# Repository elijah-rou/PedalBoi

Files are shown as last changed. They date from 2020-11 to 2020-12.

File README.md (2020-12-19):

# PedalBoi
A guitar pedal powered by the [Electrosmith Daisy](https://www.electro-smith.com/daisy/daisy) microcontroller platform. The goal is to have a fully programmable pedal that can be customised with any effect via digital signal processing. The programmed effect is currently a distortion, hard clipping the input.

Why create something like this? Individual guitar pedals are quite expensive and the signal chain can get cumbersome/complex if you have many pedals. So being able to program any effect (or multiple), into a single pedal solves for both these things. Combined with on demand upload, this would be a great addition to a guitarist's arsenal!

## Functionality
### Core:
* ~~Circuit Design with Audio Buffers~~
* ~~Distortion Effect~~
*  ~~60Hz Noise removal~~
* ~~3PDT Switch Integration~~
*  ~~Initial prototype with premade enclosure~~
* Implement Potentiometer

### Future Work
* Create a PCB design with mountable female headers for the Daisy Seed and USB-C power delivery/USB passthrough
* Create a custom 3D (printable) enclusure
* Create mounting hardware for PCB and internal components for custom enclosure
* Implement bluetooth module for wireless effect uploading 
* Create web/app interface to facilitate wireless effect upload
* Live control of effect via an app

## Usage
Compile PedalBoi.
```makefile
make
```

Upload binary to Daisy.
```makefile
make program-dfu
```

## Bill of Materials and Schematic

### Documentation
For a detailed bill of core materials, consult this [document](bom.pdf).

Any enclosure may be used, such as the [aluminium console](https://www.digikey.com/en/products/detail/lmb-heeger-inc/MDC752-PLAIN/1738) which was chosen for the initial prototype.

### Current Circuit Schematic
The circuit consists of three major parts; the input buffer (left), the output buffer (right) and the Daisy seed microcontroller (middle). The schematic was created using [Fritzing](https://fritzing.org), check the program out! 
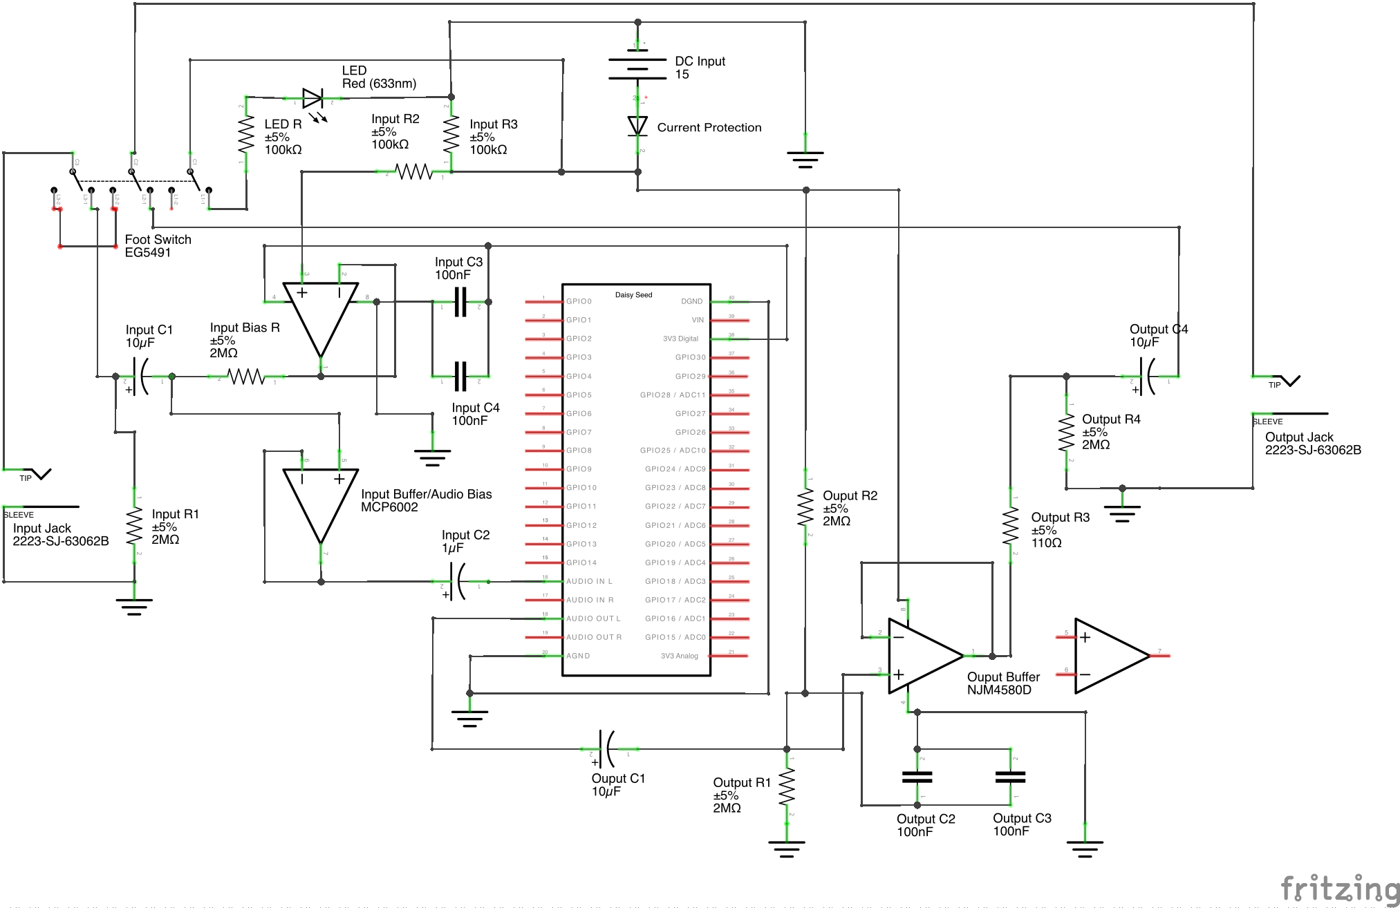
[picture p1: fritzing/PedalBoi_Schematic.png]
PedalBoi Circuit Schematic


### Material Motivation
The circuit was largely butchered from the [Daisy Petal schematic](https://github.com/electro-smith/Hardware/blob/master/reference/daisy_petal/ES_Daisy_Petal_Rev5.pdf) with most of the circuit design and components being the same, though it is heavily simplified and uses breadboard compatible components as opposed to TSSOP. This was mostly done as I had never designed an audio sensitive analog circuit like this before. With regards to casing and the footswitch, those were recommendations given by my Professor (thanks Wendy!)

The goal was to use as much established literature as I could in order to focus on actually building and refinining the pedal (as it turns out, analog electrical issues are hard and took up all my time).

## Major components

### Input Buffer
The first core component of the project is the input buffer circuit, which effectively allows us to take a high impedance signal and transform it into a low impedance signal. This is important as the pickups of any electric guitar are high impedance and do not allow much current to flow through them. Using the Op-Amps of the MCP6002 IC, we can both bias the input to a specific voltage and ensure that signal is unity gain. This results in a cleaner, undistorted signal.

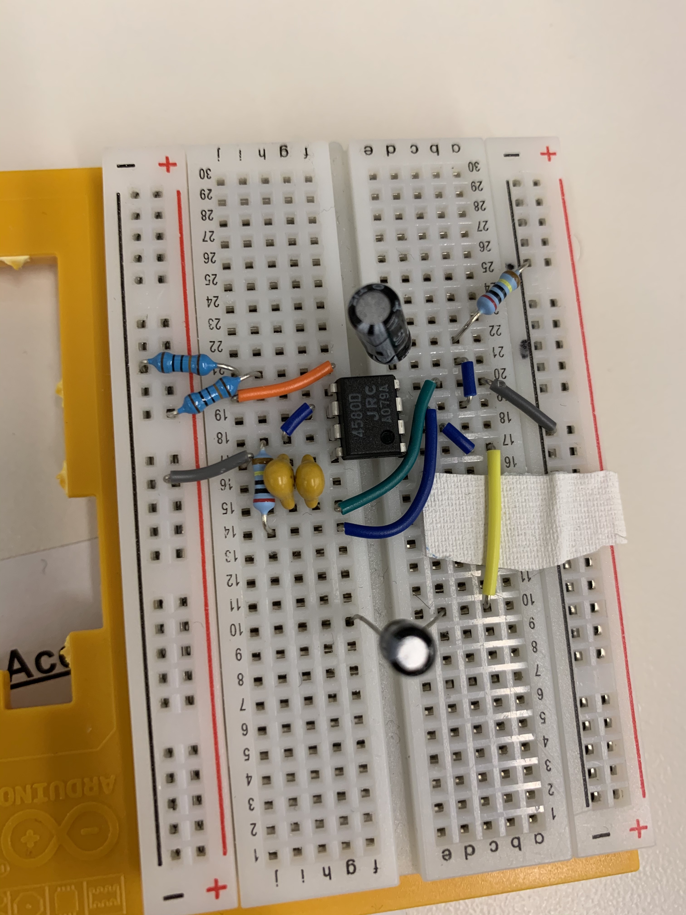
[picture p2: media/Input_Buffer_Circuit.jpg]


### Output Buffer
Similarly to the input buffer, the output buffer circuit ensures our signal remains at unity gain. In this case, we use an Op-Amp designed to handle higher voltage signals and spikes specifically for audio, allowing the circuit to handle effects like high-gain distortion.

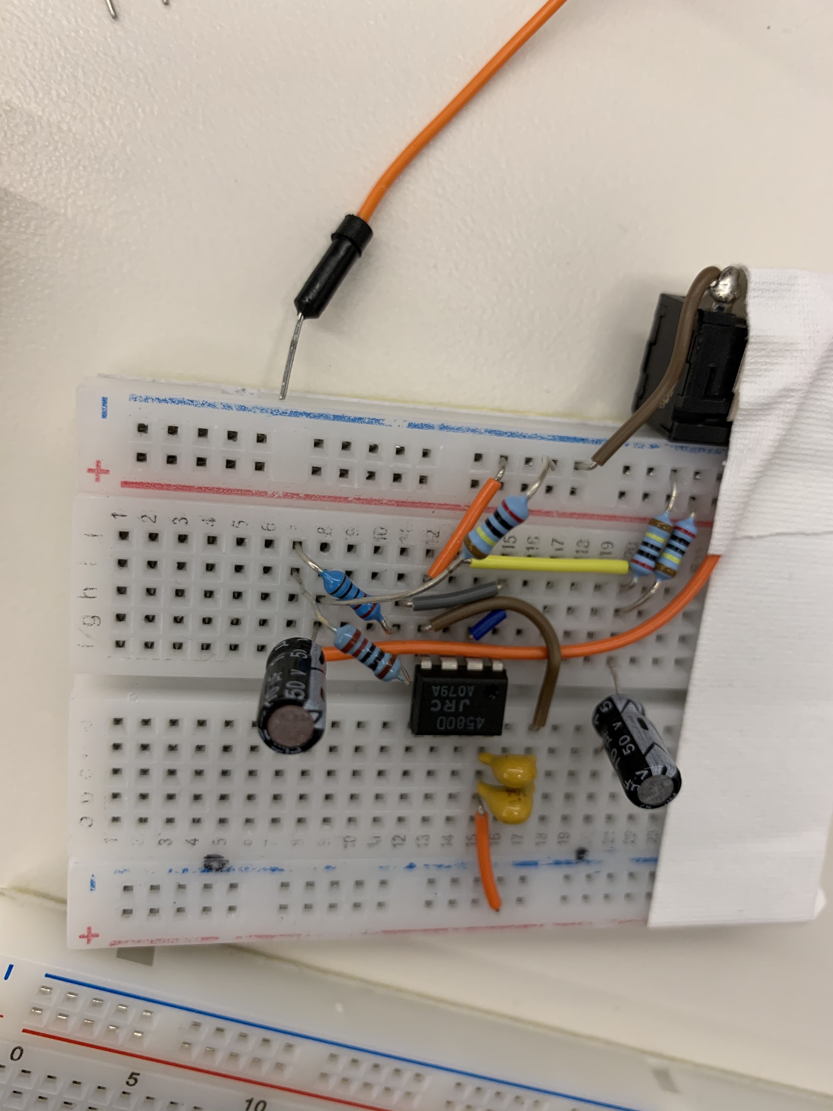
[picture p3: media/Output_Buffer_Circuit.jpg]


### 3PDT Switch
The 3PDT switch allows the input and output jacks to be directly wired to eachother when the switch is off, and connected to the processing circuit when the switch engaged. This is crucial in ensuring the least amount of noise possible when the pedal is off. A resource explaining how this is acheived can be found [here](https://www.coda-effects.com/2015/03/3pdt-and-true-bypass-wiring.html). 



### Enclosure
Points for mounting holes were determined via cross-section as shown in the photo below. For the V1 prototype, a drill with  tips matched to the component dimensions was used to create mounting holes on both the top half of the enclosure and the bottom half. Finally, the enclosure was brushed with sandpaper.

Top Half:
* 2 holes for the LED and potentiometer (to be implemented)
* One large hole for the footswitch

Bottom Half:
* 2 holes on either side for the input and output jacks.

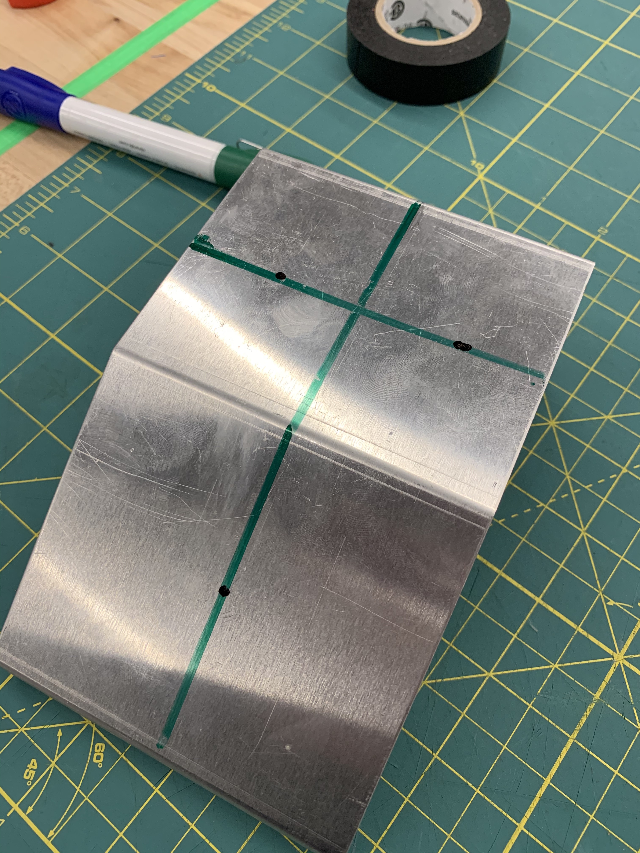
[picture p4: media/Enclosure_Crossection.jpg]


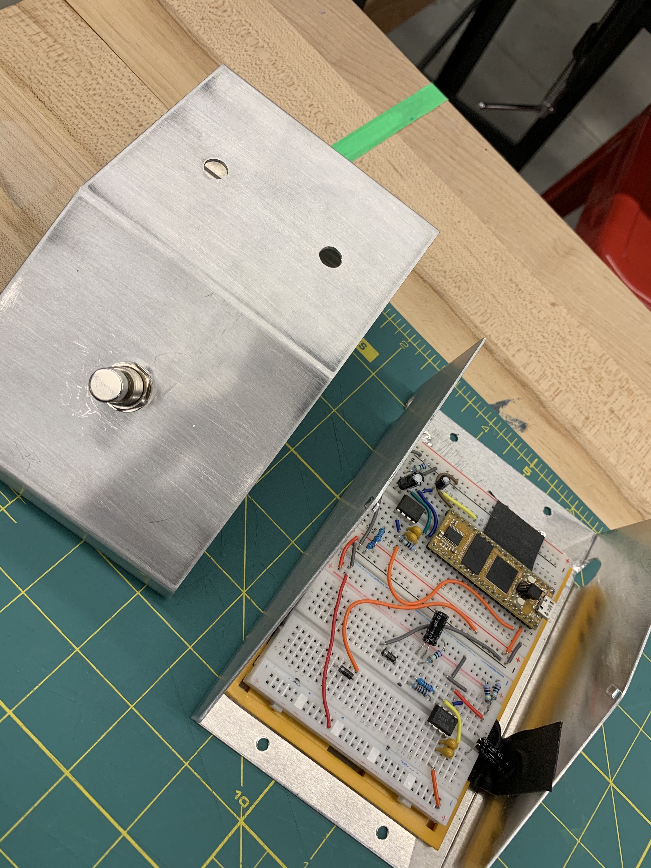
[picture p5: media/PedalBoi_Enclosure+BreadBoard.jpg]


### Daisy Seed
The Daisy Seed is a microcontroller specifically designed for audio processing and synthesis. It comes packaged with a variety of components needed for audio applications, including multiple Analog-Digital Converters, Digital-Analog Converters, (stereo) audio input/output and a fast M7 microprocessor with enourmous cache allowing for memory heavy effects such as complex *delay*. There are also an array of libraries included with the platform to both program the board and conduct DSP on analog input signals using C++. See [PedalBoi.cpp](PedalBoi.cpp) for distortion implementation details.

* Daisy Interface Library - [libdaisy](https://github.com/electro-smith/libDaisy)
* DSP Library - [DaisySP](https://github.com/electro-smith/DaisySP)



## Final Build
The final build comprised of the modified aluminium console containing the breadboard prototypes and 3PDT Switch, secured with 2 screws at the bottom of the console. Any 13-18V DC power source can be used to power the pedal via a positive and negative lead extending outside the case.


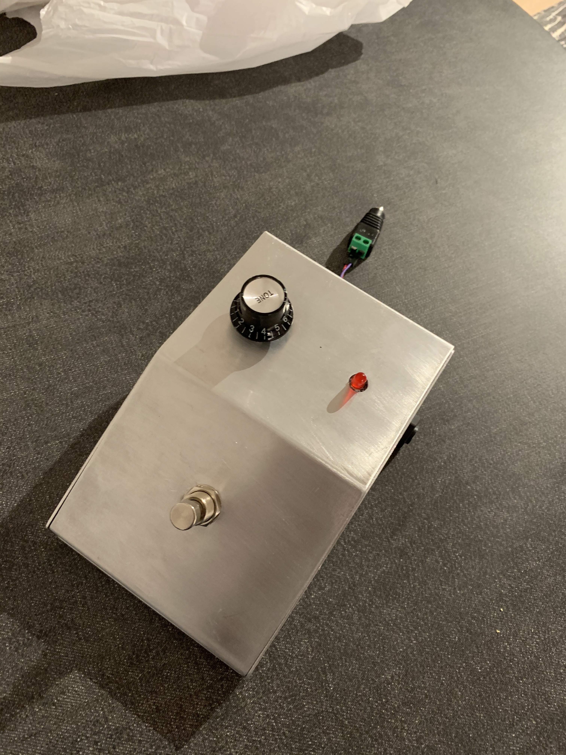
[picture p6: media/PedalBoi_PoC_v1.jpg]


## V1 Reflections
This was a great initial foray into processing real analog signals digitally and was lots of fun to build an initial proof of concept. However, there were a few significant issues throughout this V1 iteration:

### Ground loops
Ground loops caused by different AC power sources were a substantial source of noise in the initial design of the pedal. It was tough to analyse and debug where the noise was actually coming from. Eventually, the entire circuit had to be redesigned with the help of an Oscilloscope to weed out the hum.

### Incorrect Op-Amp functionality
The NJM4580D is a great Op-Amp for audio applications. However there is one substantial problem; it does not support rail-rail power. This proved to be an issue in the initial circuit design, which only supplied 5V via breadboard rails resulting in a power differential in the Op-Amp which caused it to malfunction. Luckily, the problem could be solved by applying more voltage over the NJM4580D Op-Amp, while simultaneously supplying the MCP6002 Op-Amps with the 3V3 supply directly from the Daisy Seed.

### Lack of space due to breadboards and prebuilt enclosure
As V1 used a prebuilt enclosure and a breadboard prototype, there was little space leftover for the audio jacks at the back of the case (resulting in the input audio jack being skew). This also made it impossible to mount the DC barrel plug inside the case, as the plug needed to be elevated. In the future, this can be solved with the combination of a custom PCB, custom enclosure and internal mounting brackets.

## Oscilloscope Breadboard Demo
Osc Demo (https://youtu.be/5Jb7ozU0aHI "Oscilloscope Demo")

## PedalBoi_v1 Demo:
v1 Demo (https://youtu.be/re2_l2MvA74 "PedalBoi_v1 Demo")

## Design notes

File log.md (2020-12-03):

## 13/11
Received initial components to prototype with.

This includes:
+ [Electrosmith Daisy Seed](https://www.electro-smith.com/daisy/daisy) 
+ Aluminium Console
+ [MCP6002-I/P-ND General Purpose OpAmp for input buffering](https://www.digikey.com/en/products/detail/microchip-technology/MCP6002-I-P/500875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)
+ [NJM4580D-ND Audio OpAmp for output buffering](https://www.digikey.com/en/products/detail/njr-corporation-njrc/NJM4580D/673772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)
+ [2 1/4" audio jacks (2223-SJ-63062B-ND)](https://www.digikey.com/en/products/detail/cui-devices/SJ-63062B/13155750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)

The initial plan is to build a simple circuit with OpAmps, the jacks and the 5V power supply I have, and have audio simply pass through the Daisy board. The next step will be to program an effect.

## 22/11
Designed initial simple prototype. Simply takes in an audio signal and outputs the same signal. See `prototype_1.asc` for sim.
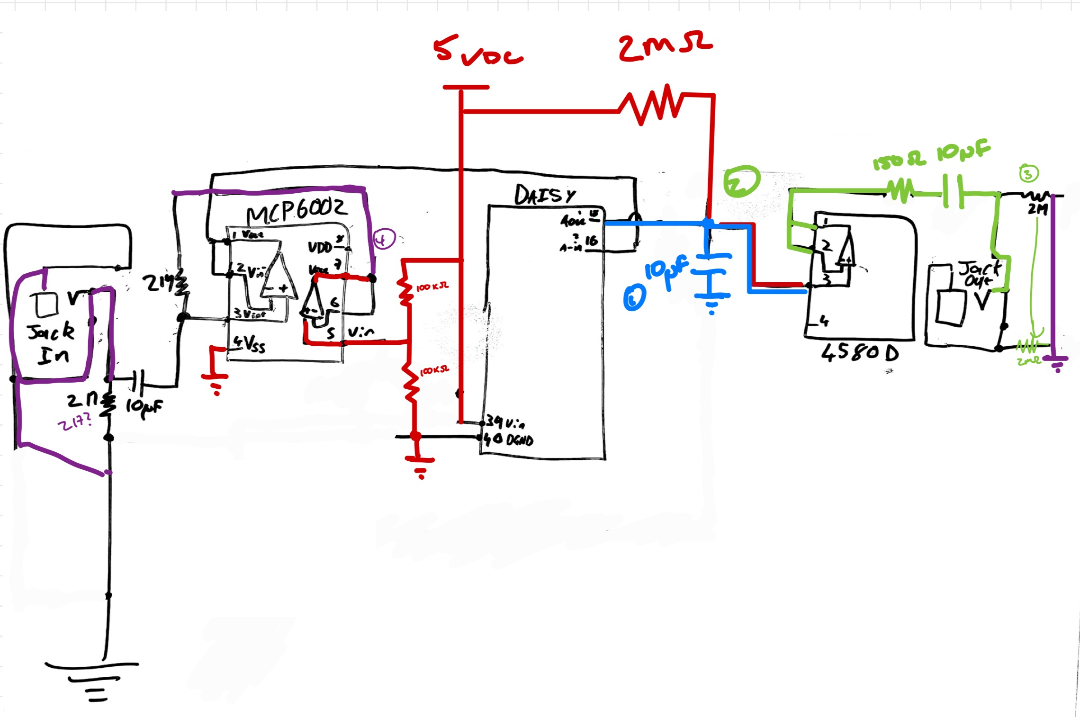
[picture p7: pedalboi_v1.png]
PedalBoi Schematic v1


## 25/11
Refined the initial circuit. Coded distortion effect on Daisy and uploaded it to the board (See `PedalBoi.cpp`). 
Built out breadboard prototype.

## 28/11 - 29/11
Changed effect to temporarily be in-out passthrough. Tested Initial breadboard prototype. 
There is a hum that I *can not* seem to locate the source of, though the guitar signal gets through the daisy. 
Modularised the breadboard prototype for debugging.

## 02/12
Swapped out AC power adapter for a 9V battery. This has eliminated most of the AC noise.
Added a resistor from output circuit to ground -> Eliminates the ground loop when the circuit is off.
Added a capacitor to the 2nd op amp output of the input circuit to attempt to eliminate stray DC input.

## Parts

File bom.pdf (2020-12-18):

Fritzing Bill of Materials | 2020/12/18, 18:36
file:///Users/elijahrou/Documents/PedalBoi/fritzing/PedalBoi_bom.html | Page 1 of 3

# Bill of Materials: PedalBoi_Schematic_2.fzz

/Users/elijahrou/Documents/PedalBoi_Schematic_2.fzz
Friday, December 18 2020, 15:53:46

# Assembly List

Label | Part Type | Properties

### Current

Protection | Diode | variant hv; package diode-hv
DC Input | DC Power | voltage 15; type dc power supply

### Foot Switch

### NKK M2032SS1W01 3PDT Toggle Switch

switching circuit 3PDT; variant Solder ligs, can be board mounted or through hole; package THT; part # EG5491

Input Bias R | 2MΩ Resistor | tolerance ±5%; resistance 2MΩ; package 0805 [SMD]

### Input Buffer/Audio Bias

| Dual Op-Amp | channels dual; package dip08; part # MCP6002
Input C1 | Electrolytic
| Capacitor | voltage 6.3V; capacitance 10µF; package 0405 [SMD, electrolytic]
Input C2 | Electrolytic
| Capacitor | voltage 6.3V; capacitance 1µF; package 0405 [SMD, electrolytic]
Input C3 | Ceramic Capacitor | voltage 6.3V; capacitance 100nF; package 100 mil [THT, multilayer]
Input C4 | Ceramic Capacitor | voltage 6.3V; capacitance 100nF; package 100 mil [THT, multilayer]
Input Jack | 1/4 inch mono jack | size 6.3mm; variant variant 1; package audio-jack-6.5mm-panel-mount;
| | part # 2223-SJ-63062B
Input R1 | 2MΩ Resistor | tolerance ±5%; resistance 2MΩ; package 0805 [SMD]
Input R2 | 100kΩ Resistor | tolerance ±5%; resistance 100kΩ; package 0805 [SMD]
Input R3 | 100kΩ Resistor | tolerance ±5%; resistance 100kΩ; package 0805 [SMD]
LED | Red (633nm) LED | color Red (633nm); package 0805 [SMD]
LED R | 100kΩ Resistor | tolerance ±5%; resistance 100kΩ; package 0805 [SMD]
Ouput Buffer | Dual Op-Amp | channels dual; package dip08; part # NJM4580D

file:///Users/elijahrou/Documents/PedalBoi/fritzing/PedalBoi_bom.html | Page 2 of 3
Ouput C1 | Electrolytic
| Capacitor | voltage 6.3V; capacitance 10µF; package 0405 [SMD, electrolytic]
Ouput R2 | 2MΩ Resistor | tolerance ±5%; resistance 2MΩ; package 0805 [SMD]
Output C2 | Ceramic Capacitor | voltage 6.3V; capacitance 100nF; package 100 mil [THT, multilayer]
Output C3 | Ceramic Capacitor | voltage 6.3V; capacitance 100nF; package 100 mil [THT, multilayer]
Output C4 | Electrolytic
| Capacitor | voltage 6.3V; capacitance 10µF; package 0405 [SMD, electrolytic]
Output Jack | 1/4 inch mono jack | size 6.3mm; variant variant 1; package audio-jack-6.5mm-panel-mount;
| | part # 2223-SJ-63062B
Output R1 | 2MΩ Resistor | tolerance ±5%; resistance 2MΩ; package 0805 [SMD]
Output R3 | 110Ω Resistor | tolerance ±5%; resistance 110Ω; package 1206 [SMD]
Output R4 | 2MΩ Resistor | tolerance ±5%; resistance 2MΩ; package 0805 [SMD]
Seed | IC | editable pin labels false; pins 40; variant variant 4; pin spacing 100mil;
| | chip label IC; package DIP (Dual Inline) [THT]; hole size
| | 1.0mm,0.508mm

# Shopping List

Amount | Part Type | Properties
1 | Diode | variant hv; package diode-hv
1 | DC Power | voltage 15; type dc power supply
1 | NKK M2032SS1W01
| 3PDT Toggle Switch | switching circuit 3PDT; variant Solder ligs, can be board mounted or through
| | hole; package THT; part # EG5491
5 | 2MΩ Resistor | tolerance ±5%; resistance 2MΩ; package 0805 [SMD]
1 | Dual Op-Amp | channels dual; package dip08; part # MCP6002
3 | Electrolytic Capacitor | voltage 6.3V; capacitance 10µF; package 0405 [SMD, electrolytic]
1 | Electrolytic Capacitor | voltage 6.3V; capacitance 1µF; package 0405 [SMD, electrolytic]
4 | Ceramic Capacitor | voltage 6.3V; capacitance 100nF; package 100 mil [THT, multilayer]
2 | 1/4 inch mono jack | size 6.3mm; variant variant 1; package audio-jack-6.5mm-panel-mount; part #
| | 2223-SJ-63062B
3 | 100kΩ Resistor | tolerance ±5%; resistance 100kΩ; package 0805 [SMD]

file:///Users/elijahrou/Documents/PedalBoi/fritzing/PedalBoi_bom.html | Page 3 of 3
1 | Red (633nm) LED | color Red (633nm); package 0805 [SMD]
1 | Dual Op-Amp | channels dual; package dip08; part # NJM4580D
1 | 110Ω Resistor | tolerance ±5%; resistance 110Ω; package 1206 [SMD]
1 | IC | editable pin labels false; pins 40; variant variant 4; pin spacing 100mil; chip label IC; package DIP (Dual Inline) [THT]; hole size 1.0mm,0.508mm

Exported with Fritzing 0.9.4- http://fritzing.org

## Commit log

2020-12-18 Add Fritzing files; Clean up code; Add Youtube links for demos;
    [PedalBoi_Schematic.fzz]
2020-12-18 add pdf bom
2020-12-18 Update readme with schematic and bom links
